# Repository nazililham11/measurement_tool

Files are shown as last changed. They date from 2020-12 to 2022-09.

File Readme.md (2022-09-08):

# Measurement Tool
## Android

***Konfigurasi Alamat Hardware***

Alamat Hardware dapat dilihat dari IP Address yang muncul pada LCD hardware 
Misal IP Address Pada LCD adalah `192.168.0.100` maka alamat nya `ws://192.168.0.100`

### Flowchart komunikasi aplikasi
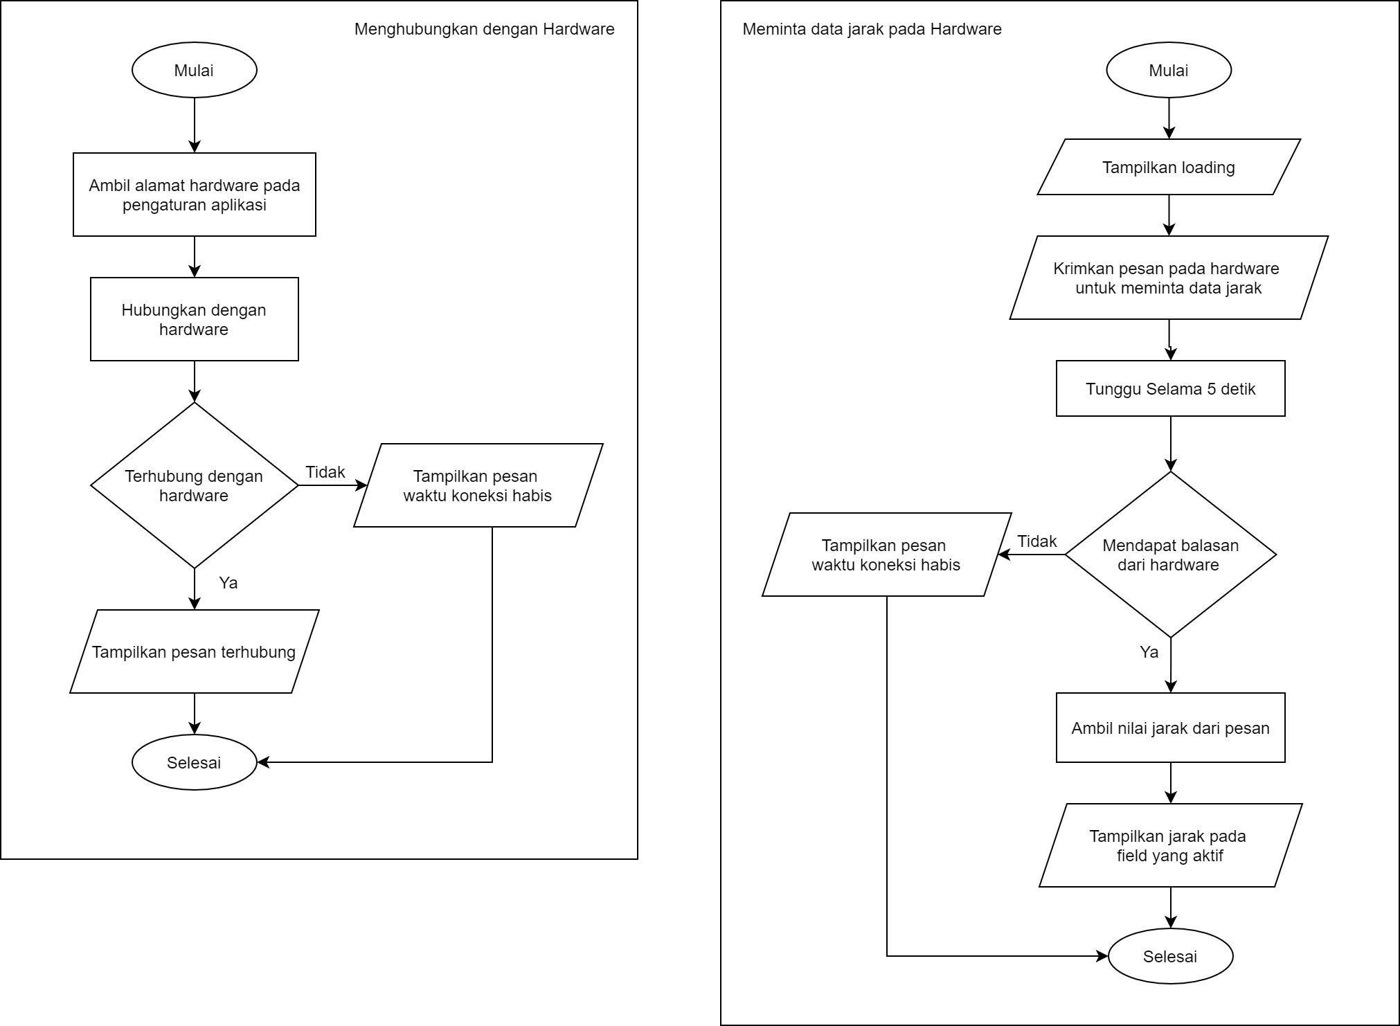
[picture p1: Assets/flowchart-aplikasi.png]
Flowchart Aplikasi


## Arduino

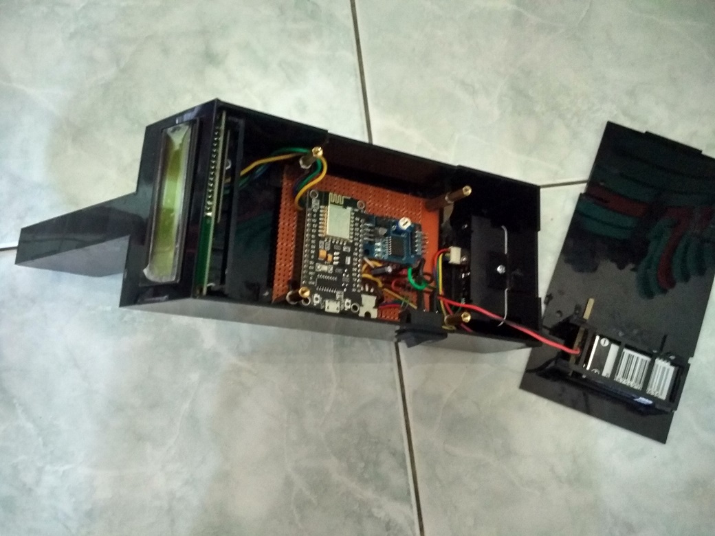
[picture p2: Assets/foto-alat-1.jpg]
Foto Rangkaian

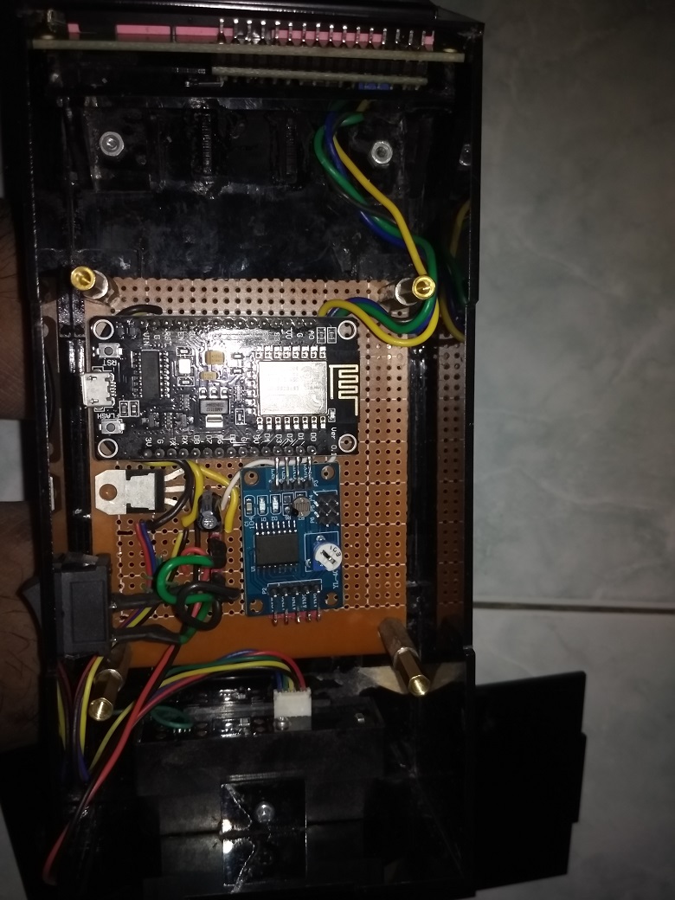
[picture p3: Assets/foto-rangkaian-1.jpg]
Foto Rangkaian

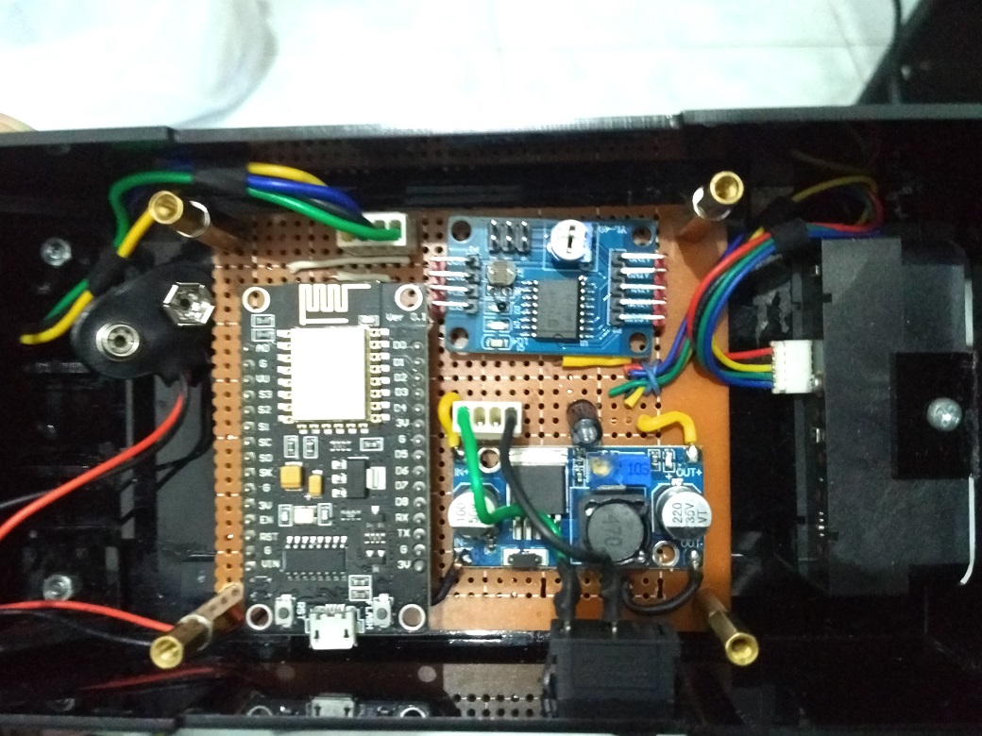
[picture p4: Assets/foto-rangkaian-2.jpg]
Foto Rangkaian


### Komponen
 - NodeMCU ESP8266
 - Sensor Jarak Sharp GP2Y0A710K0F 
 - PCF8591
 - Batterai
 - Saklar
 - LCD 16x2
 - LCD I2C Backpack/LCD to I2C Adapter

### Skema
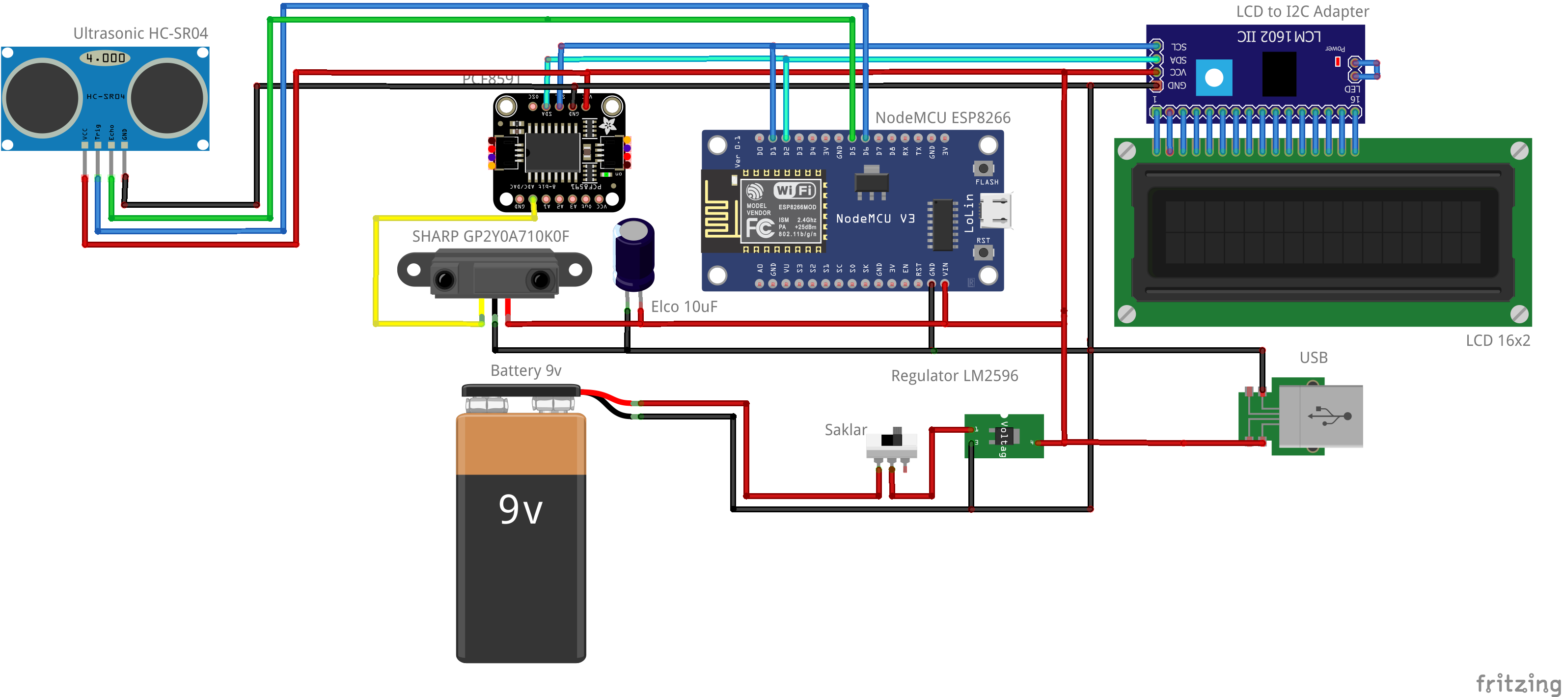
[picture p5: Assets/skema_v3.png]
Skema v2


### Library Program Arduino
 - [ESPAsyncTCP](https://github.com/me-no-dev/ESPAsyncTCP)
 - [ESPAsyncWebServer](https://github.com/me-no-dev/ESPAsyncWebServer)
 - [LiquidCrystal_I2C](https://github.com/johnrickman/LiquidCrystal_I2C)

### Flowchart Program Arduino
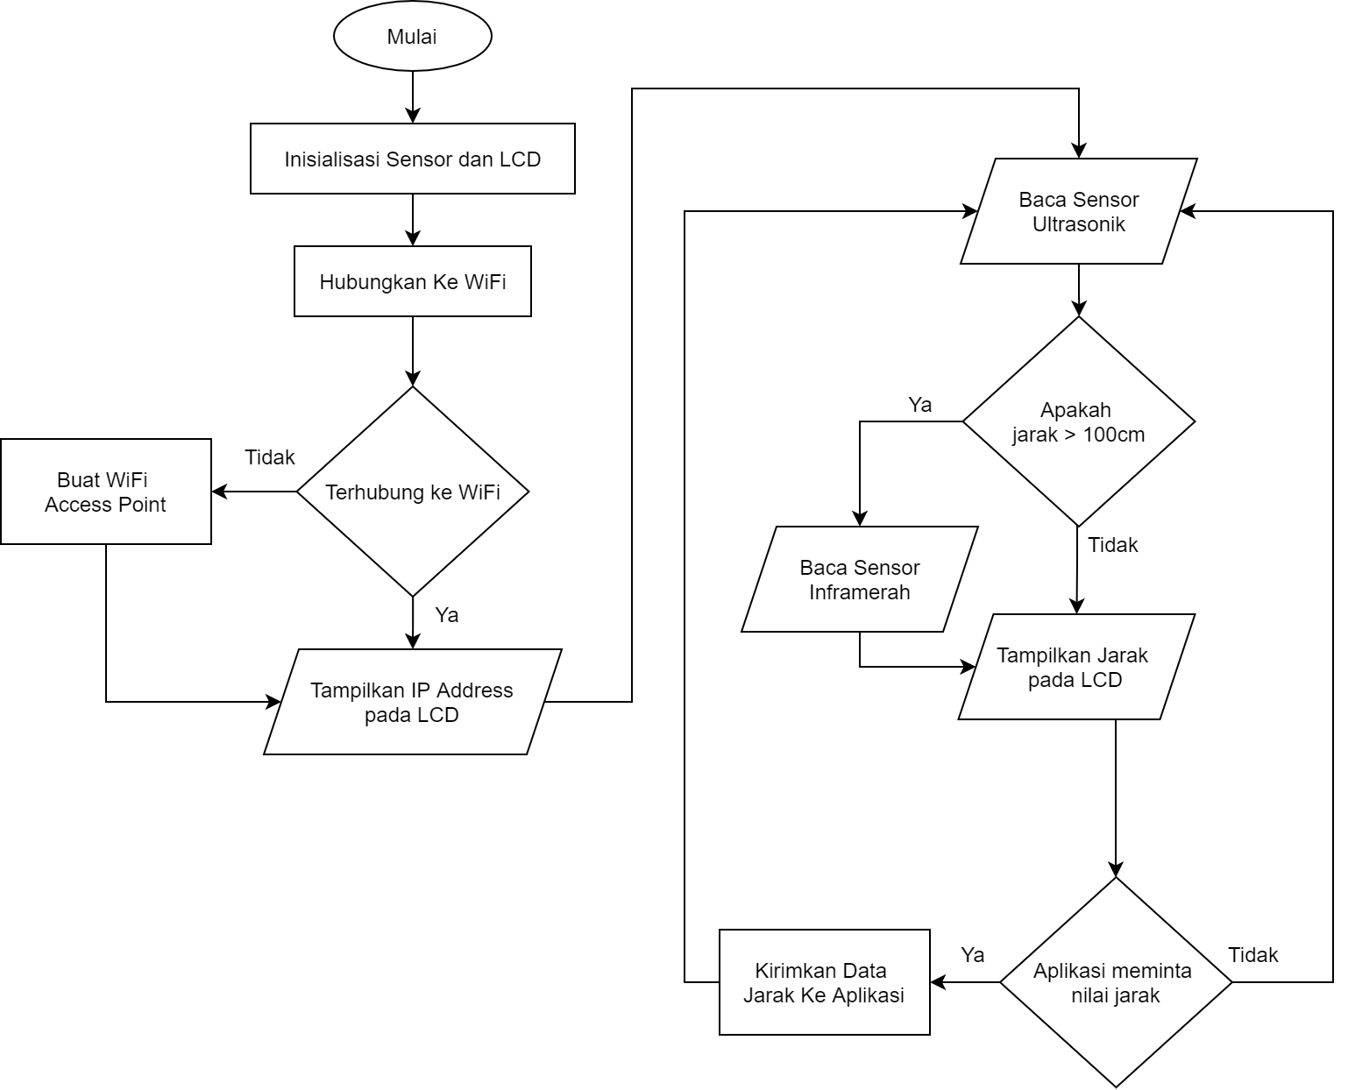
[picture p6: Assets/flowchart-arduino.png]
Flowchart Program Arduino v1


#### Konfigurasi WiFi
Terdapat dua mode pada wifi yaitu `Station` dan `Access Pont`

- Station 		: Terhubung ke wifi 
- Access Point 	: Membuat wifi hotspot

Saat dinyalakan Arduino akan mencoba untkuk terhubung ke WiFi yang ditentukan apabila setelah 15 detik arduino tidak terhubung ke WiFi maka arduino akan membuat Hotspot/Access Point sendiri 

***Konfigurasi Wifi pada mode Access Point***
```
const char* AP_WIFI_SSID            = "SoftAP";             //Access Point SSID
const char* AP_WIFI_PASSWORD        = "12345678";           //Access Point Password
```

***Konfigurasi Wifi pada mode Station***
```
const char* WIFI_SSID               = "MyWifi";				//Wifi SSID
const char* WIFI_PASSWORD           = "12345678";			//Wifi Password
```

#### Konfigurasi Sensor

Proses pengukauran dilakukan sebanyak 10 kali untuk mendapatkan nilai yang akurat. Semakin banyak proses pengukuran maka akan semakin akurat tetapi akan memakan waktu lebih lama

***Konfigurasi banyaknya proses pengukuran***
```
const uint8_t SCAN_TIMES            = 10;
```

#### Konfigurasi LCD
***Konfigurasi Alamat LCD bisa disesuaikan dengan LCD yang digunakan***

Untuk mengetahui alamat lcd bisa menggunakan program `I2C_Address_Scaner`
```
const uint8_t LCD_ADDRESS           = 0x27;
```

## Box Acrylic
Box acrylic didesain dalam bentuk 3D dahulu untuk menentukan desain, tata letak, dan posisi dari komponen, kemudian dibuat versi 2D yang akan digunakan untuk desain potongan acrylic. Proses pembuatan box menggunakan bahan acrylic dengan tebal 2mm dan dipotong menggunakan laser.

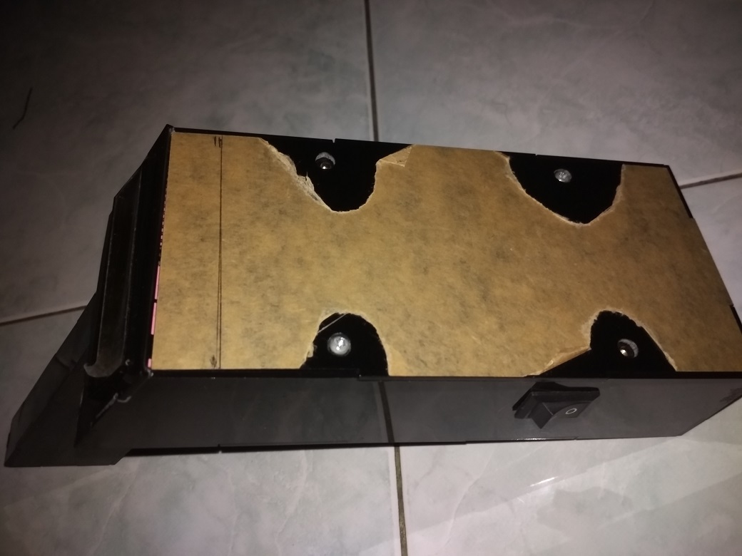
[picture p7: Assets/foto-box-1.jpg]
Foto Box Alat

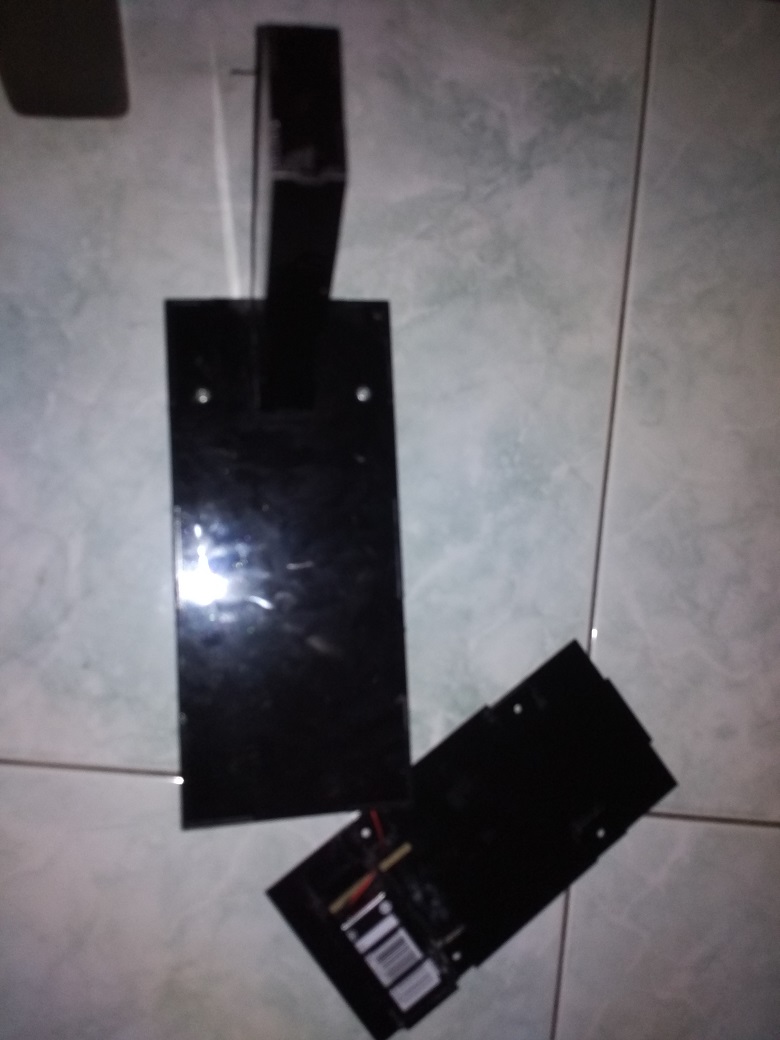
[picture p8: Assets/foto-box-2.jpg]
Foto Box Alat


### Desain 3D Box Acrylic 
Desain 3D box [box.skp](https://github.com/nazililham11/measurement_tool/raw/master/Assets/box.skp) dibuat menggunakan aplikasi google sketchup.
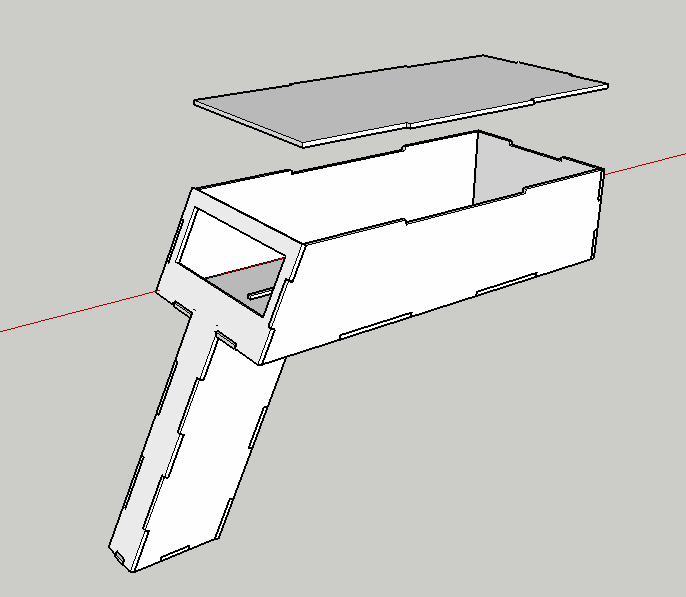
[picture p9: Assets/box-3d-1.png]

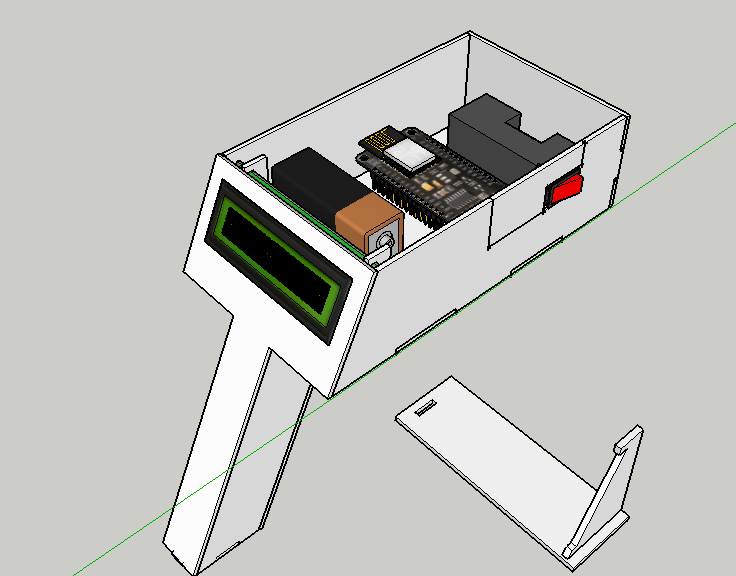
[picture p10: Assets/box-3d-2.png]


### Desain Cutting Acrylic
Desain cutting acrilic [acrylic.cdr](https://github.com/nazililham11/measurement_tool/raw/master/Assets/acrylic.cdr) di buat menggunakan aplikasi corel draw. \
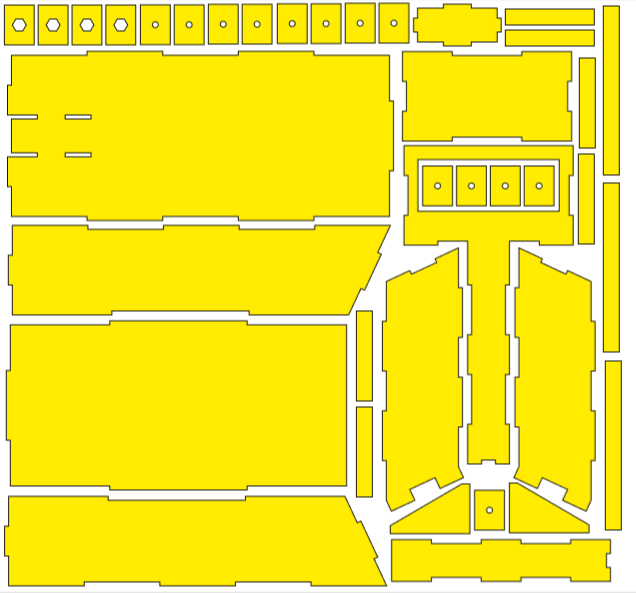
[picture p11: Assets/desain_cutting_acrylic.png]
Desain Cutting Acrylic


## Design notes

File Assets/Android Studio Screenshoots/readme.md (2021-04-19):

### Screenshoots-1
Design Activity/tampilan get started (panduan penggunaan aplikasi)<br>
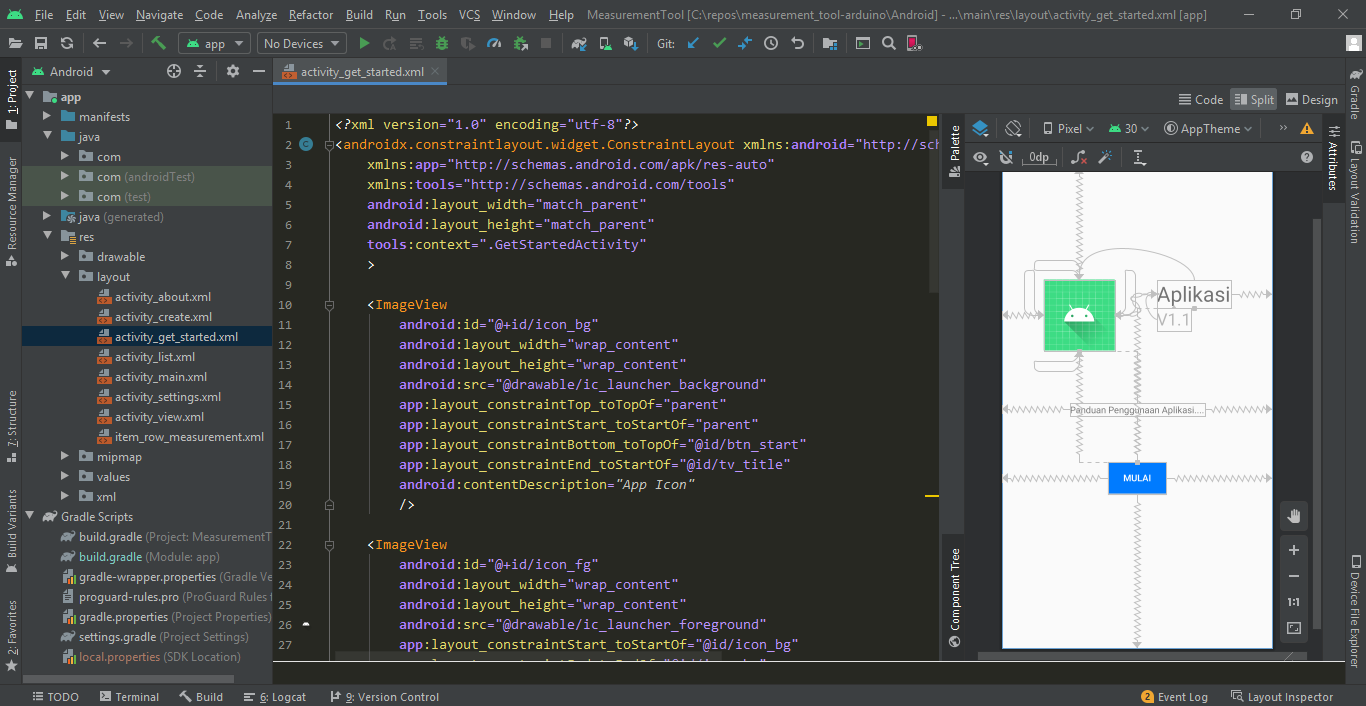
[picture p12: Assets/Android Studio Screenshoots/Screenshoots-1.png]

<br><br><br><br>

### Screenshoots-2
Design Activity/tampilan create (membuat data pengukuran baru)<br>
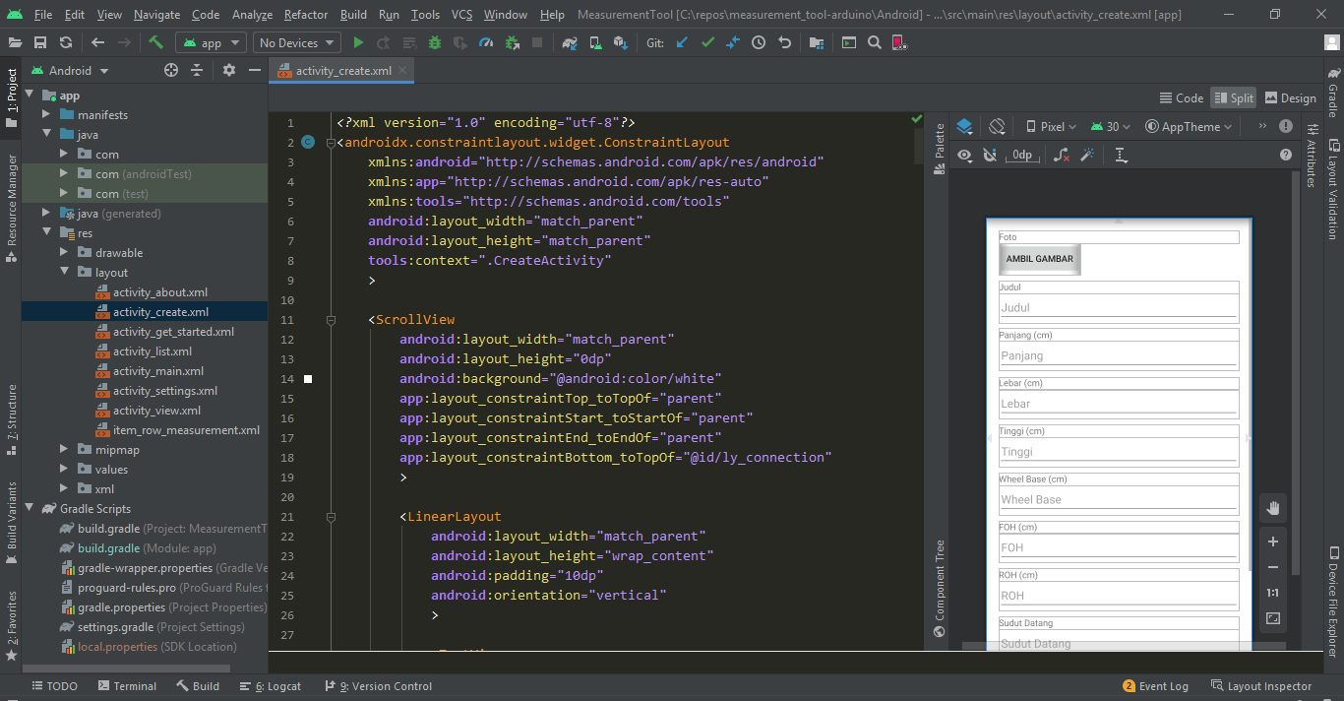
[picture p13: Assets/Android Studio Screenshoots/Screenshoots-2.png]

<br><br><br><br>

### Screenshoots-3
Design Activity/tampilan about (tentang aplikasi)<br>
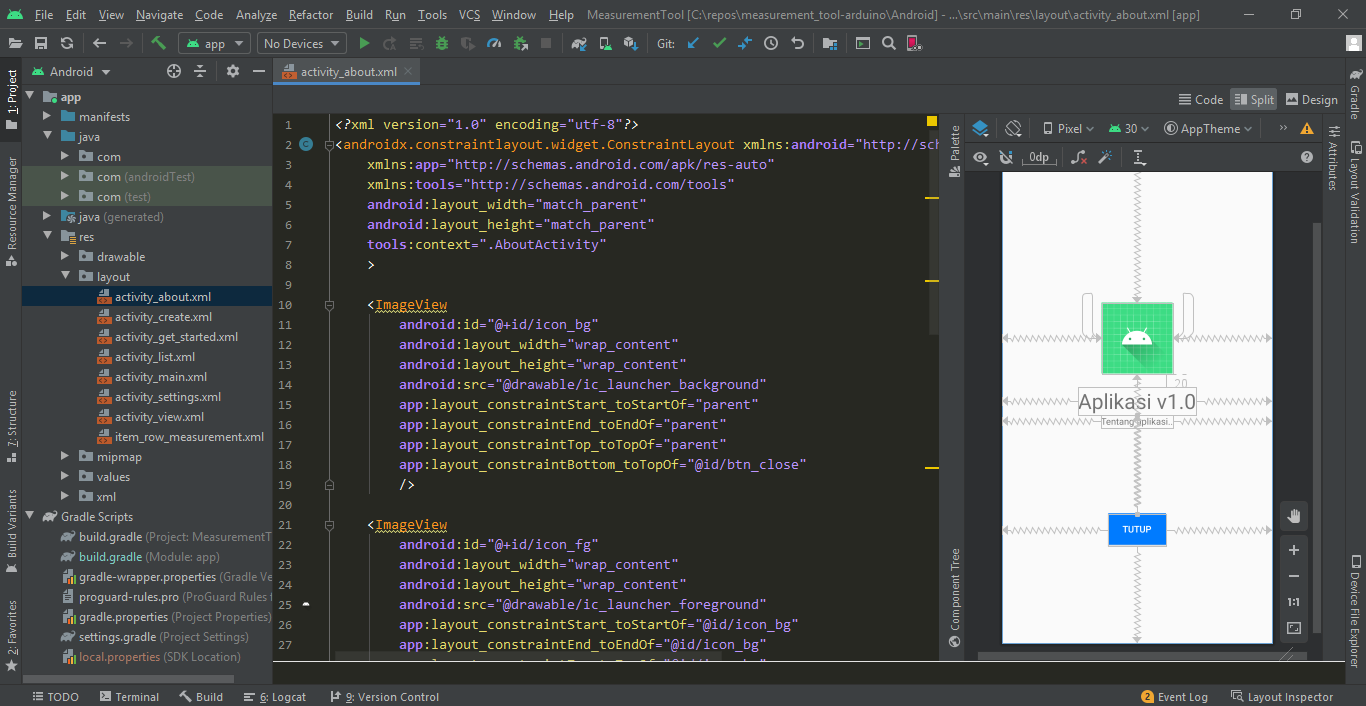
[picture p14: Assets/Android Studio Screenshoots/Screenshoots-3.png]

<br><br><br><br>

### Screenshoots-4
Design Activity/tampilan main (halaman utama)<br>
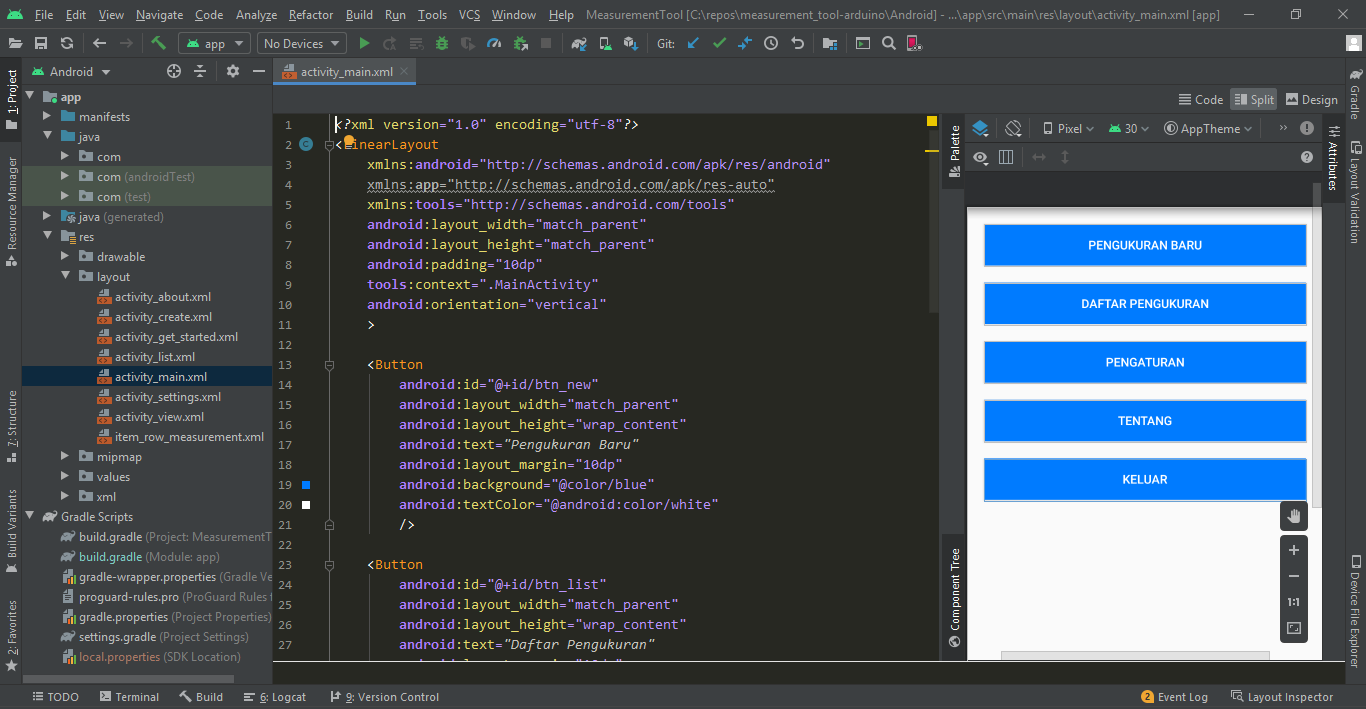
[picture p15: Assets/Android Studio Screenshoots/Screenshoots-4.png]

<br><br><br><br>

### Screenshoots-5
Design Activity/tampilan view (melihat/mengedit/menghapus data yang telah tersimpan)<br>
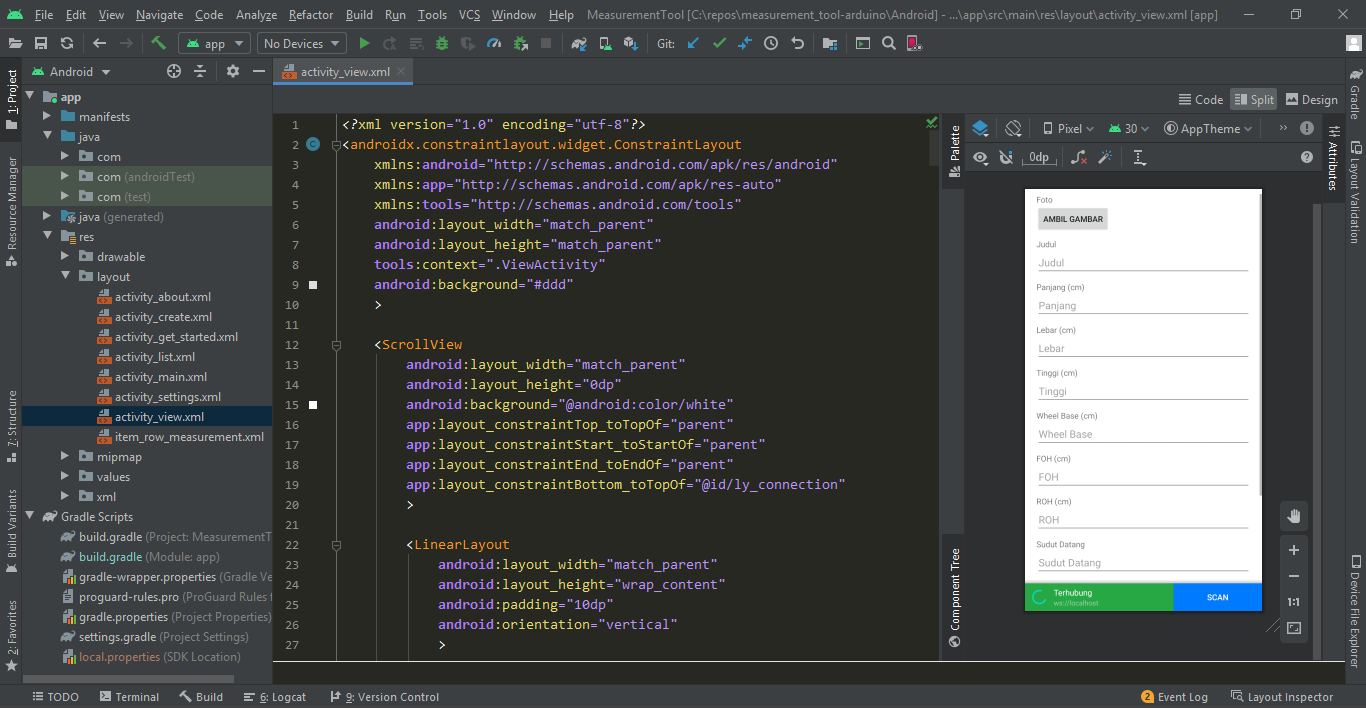
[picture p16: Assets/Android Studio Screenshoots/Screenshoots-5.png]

<br><br><br><br>

### Screenshoots-6
Design item pada list data<br>
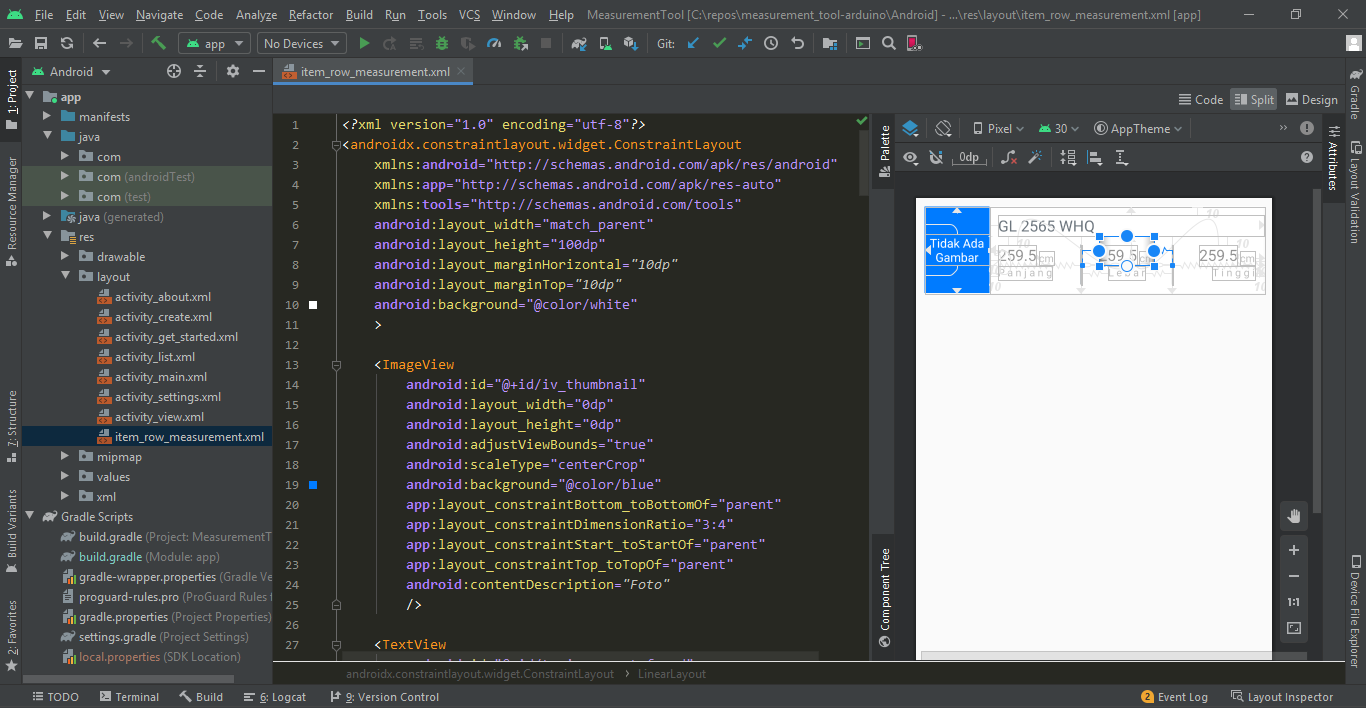
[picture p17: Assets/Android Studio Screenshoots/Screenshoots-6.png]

<br><br><br><br>

### Screenshoots-7
Program backend untuk Activity/tampilan about<br>
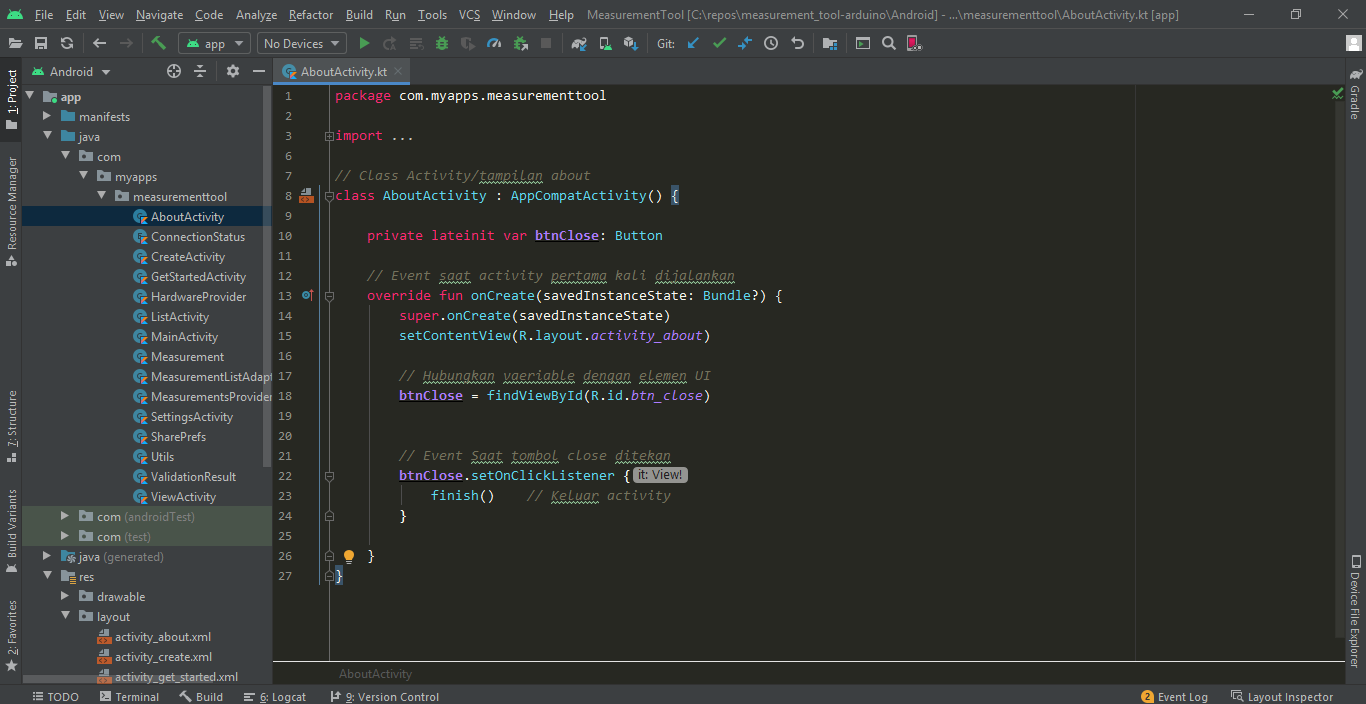
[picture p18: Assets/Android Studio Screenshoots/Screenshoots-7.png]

<br><br><br><br>

### Screenshoots-8
Program backend untuk Activity/tampilan create<br>
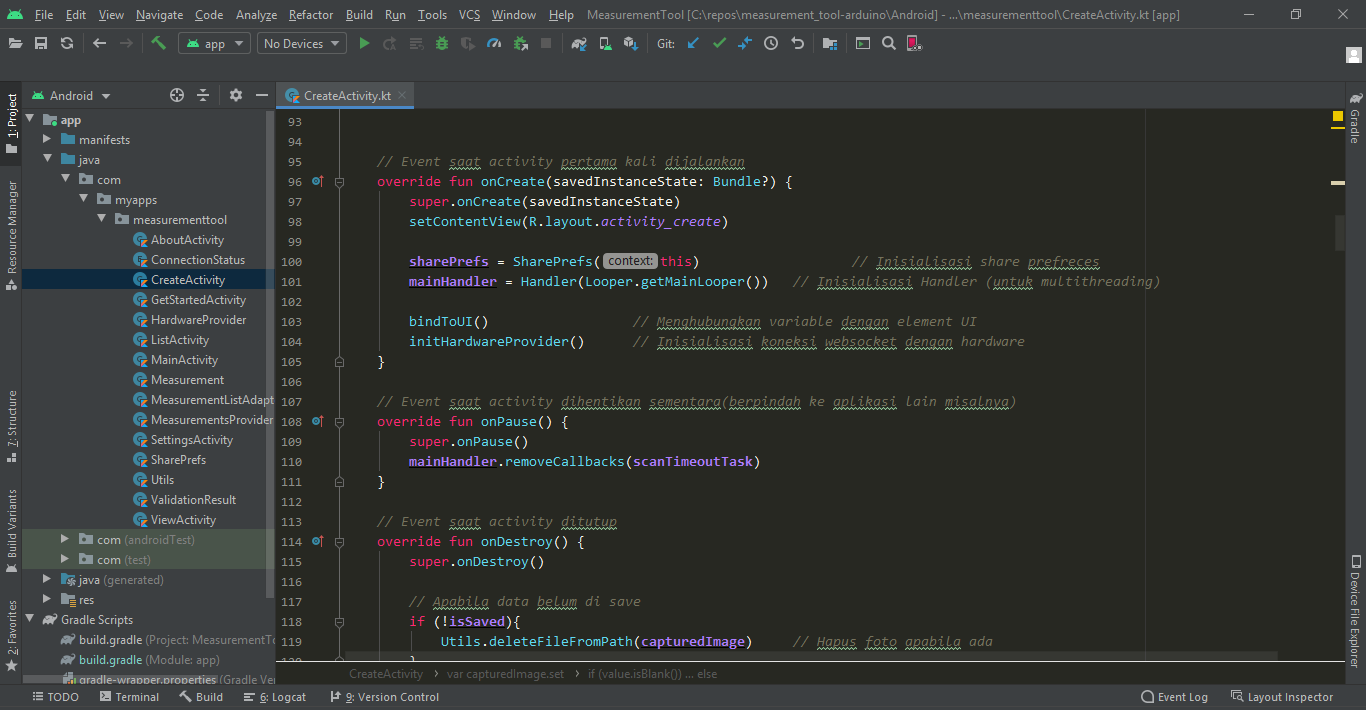
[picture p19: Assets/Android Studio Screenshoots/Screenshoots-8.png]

<br><br><br><br>

### Screenshoots-9
Program backend untuk Activity/tampilan get started<br>
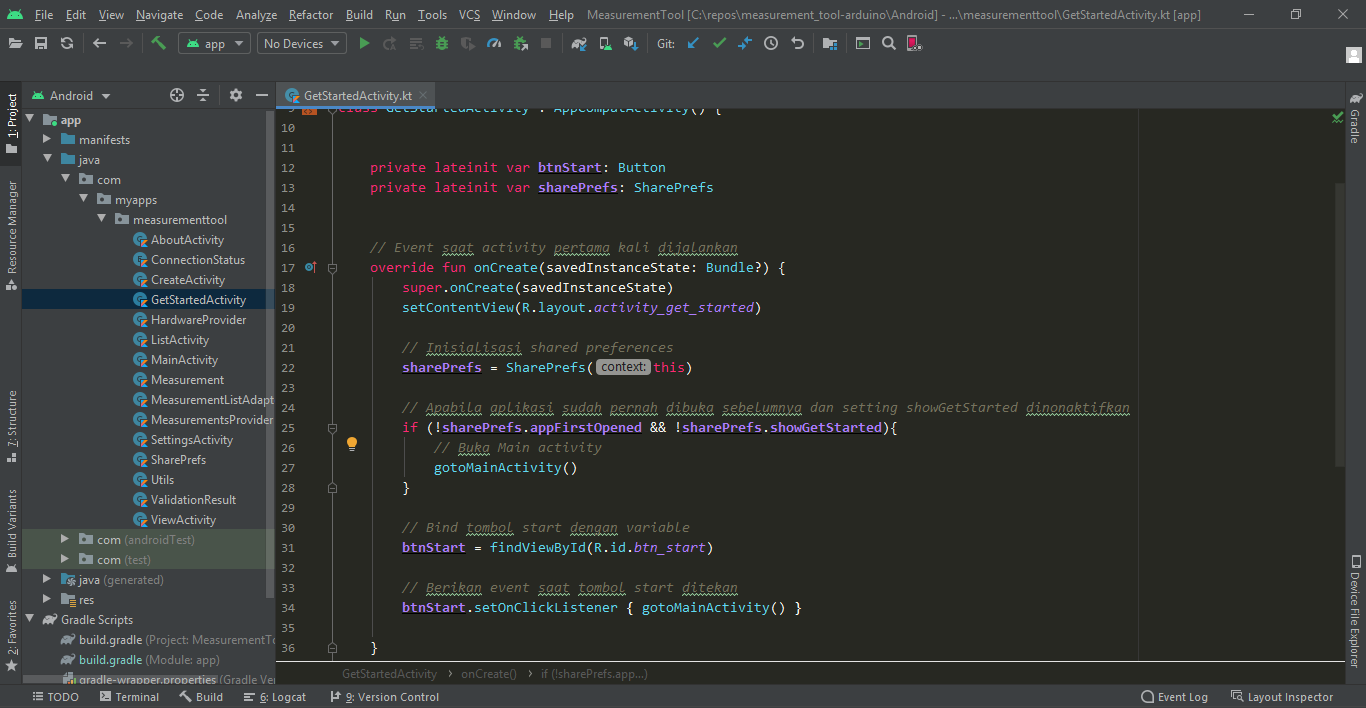
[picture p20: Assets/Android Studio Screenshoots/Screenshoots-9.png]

<br><br><br><br>

### Screenshoots-10
Program backend untuk Activity/tampilan list<br>
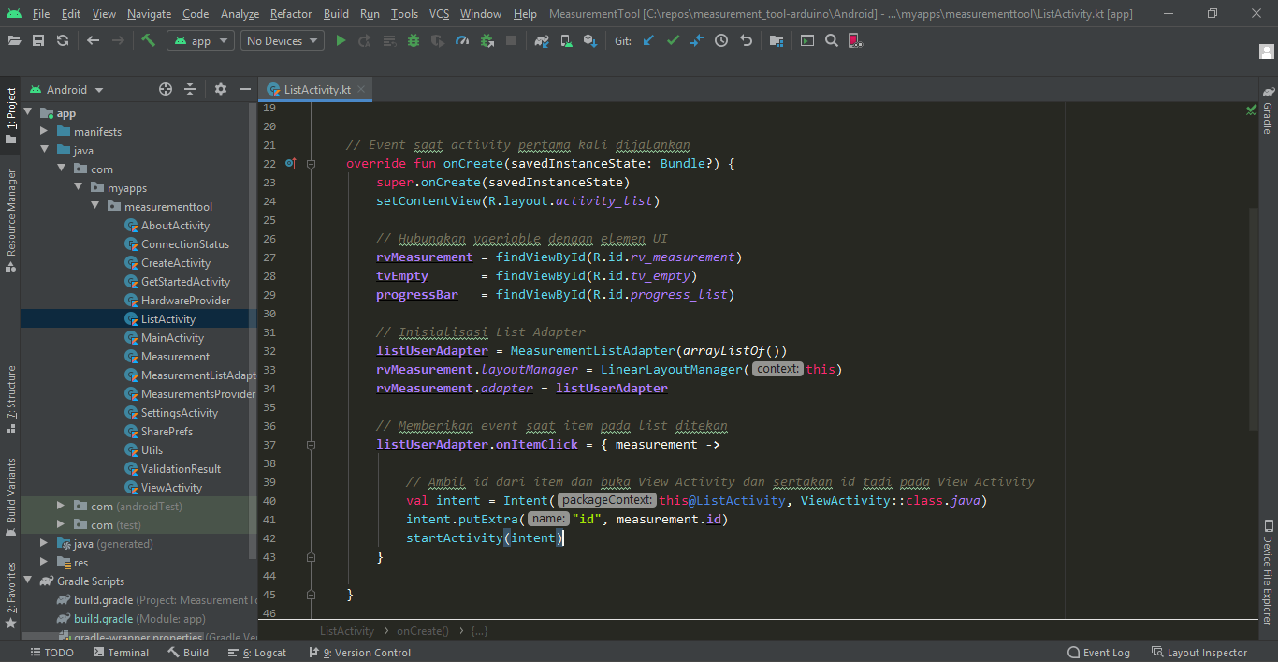
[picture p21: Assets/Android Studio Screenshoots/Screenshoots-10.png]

<br><br><br><br>

### Screenshoots-11
Program backend untuk Activity/tampilan main<br>
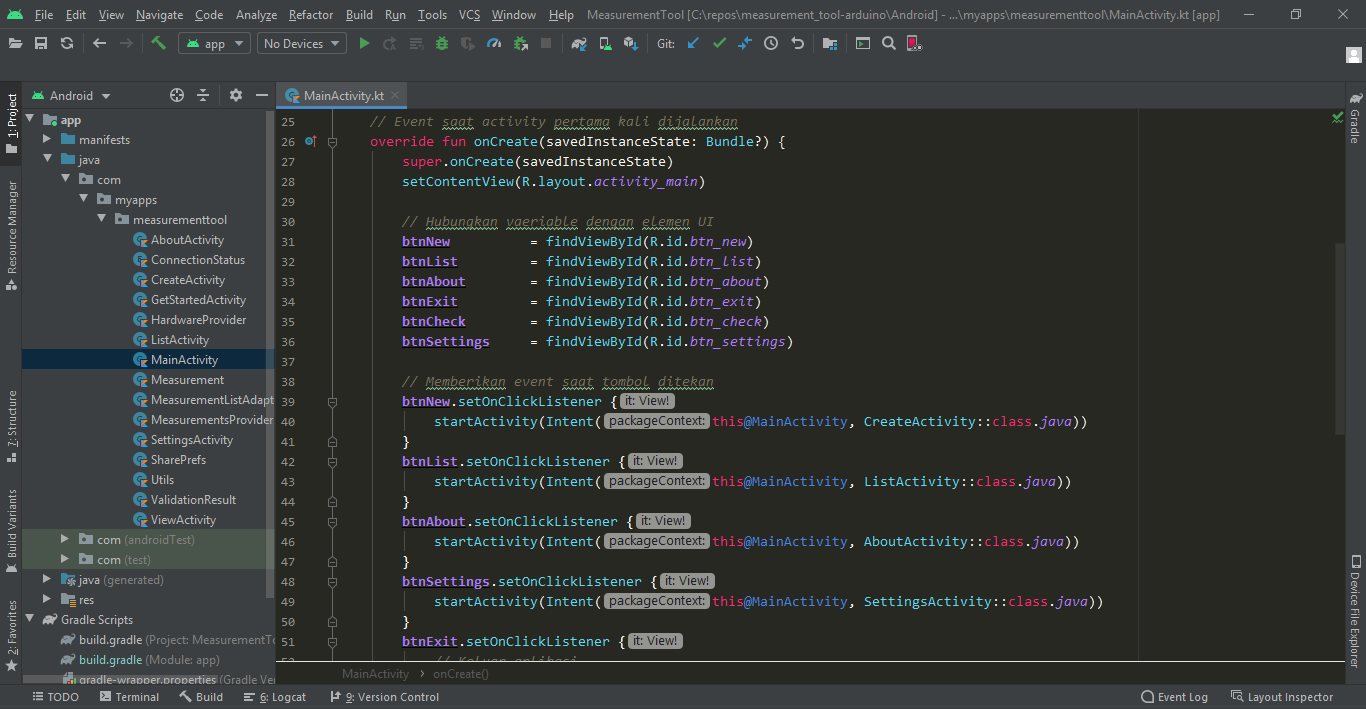
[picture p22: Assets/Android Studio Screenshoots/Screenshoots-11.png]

<br><br><br><br>

### Screenshoots-12
Program backend untuk Activity/tampilan settings<br>
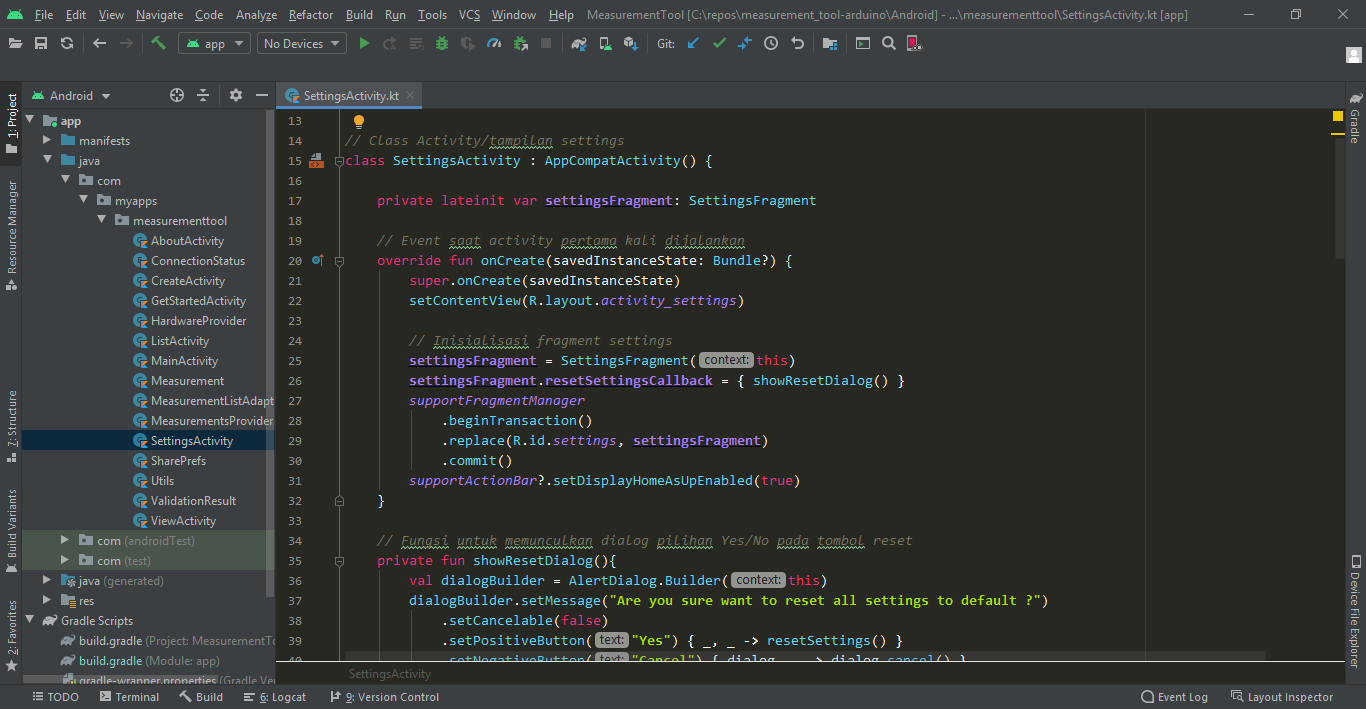
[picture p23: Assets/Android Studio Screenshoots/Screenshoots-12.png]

<br><br><br><br>

### Screenshoots-13
Program backend untuk Activity/tampilan view<br>
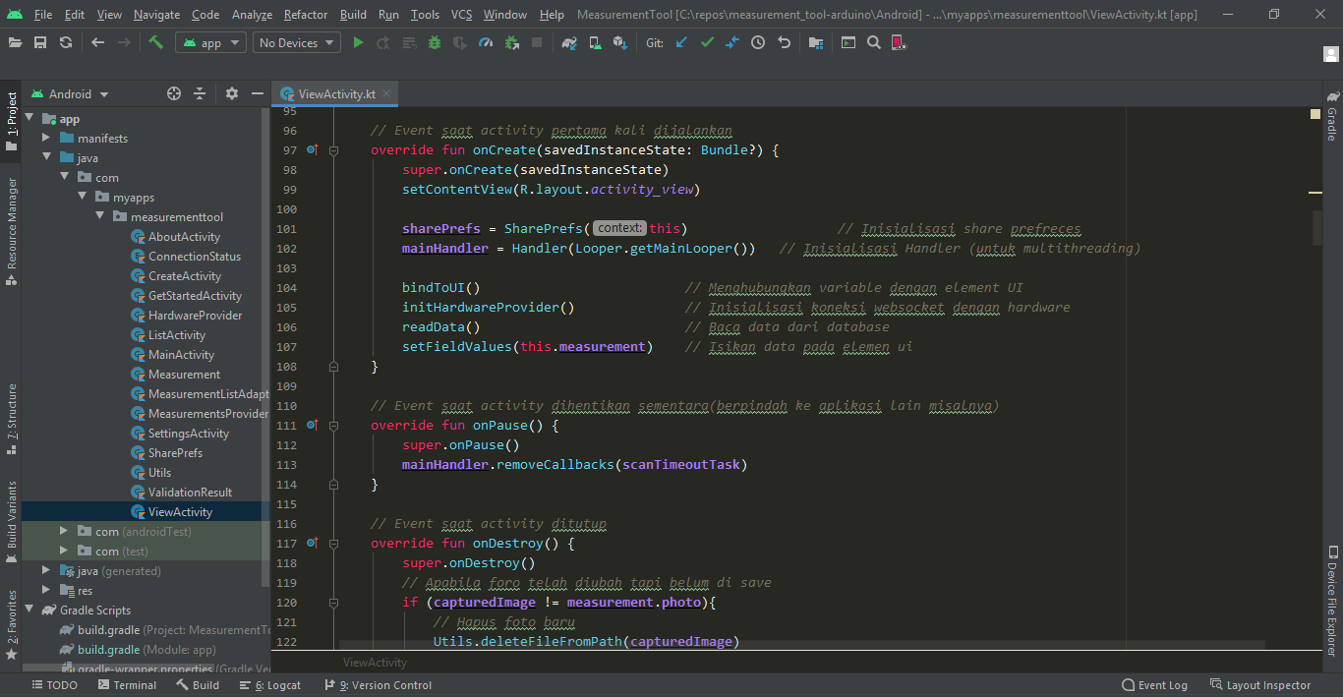
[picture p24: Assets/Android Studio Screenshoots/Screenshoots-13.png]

<br><br><br><br>

### Screenshoots-14
File konfigurasi untuk setiap string/teks pada aplikasi<br>
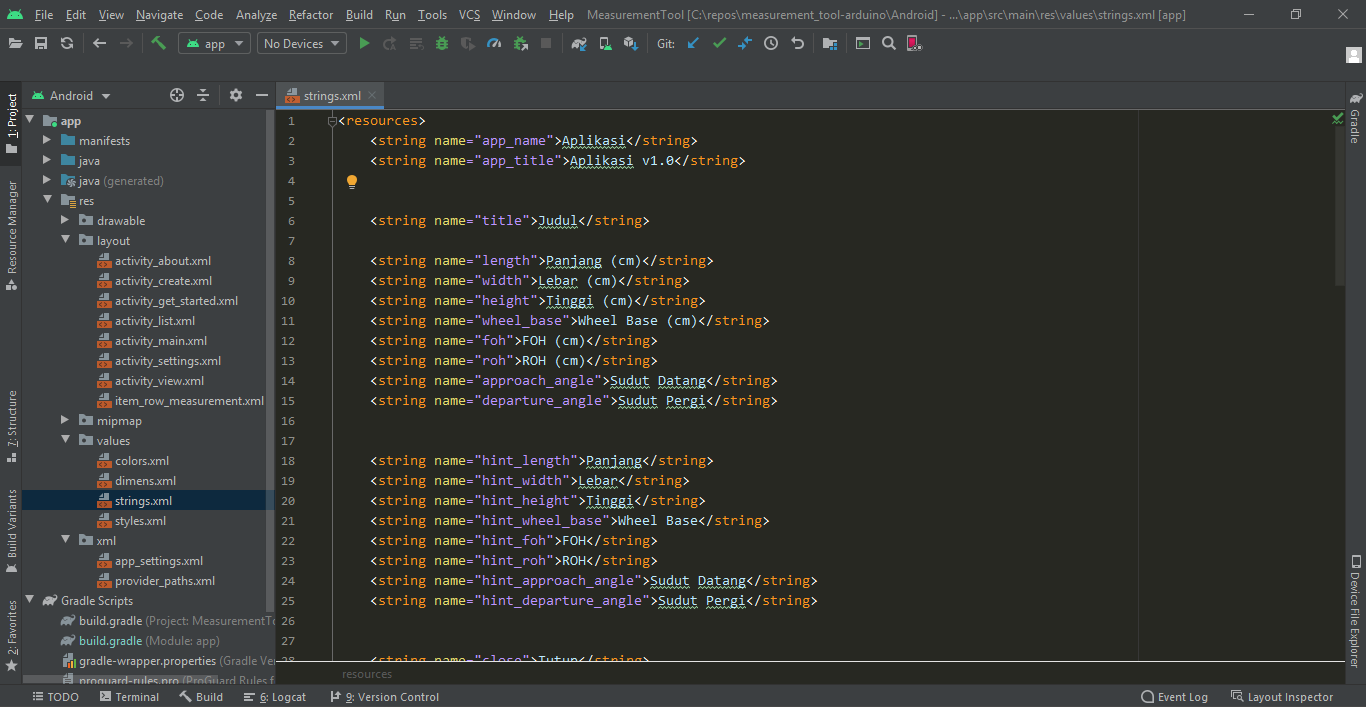
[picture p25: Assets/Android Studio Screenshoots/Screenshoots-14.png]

<br><br><br><br>

### Screenshoots-15
File konfigurasi untuk menentukan elemen yang terdapat dalam settings<br>
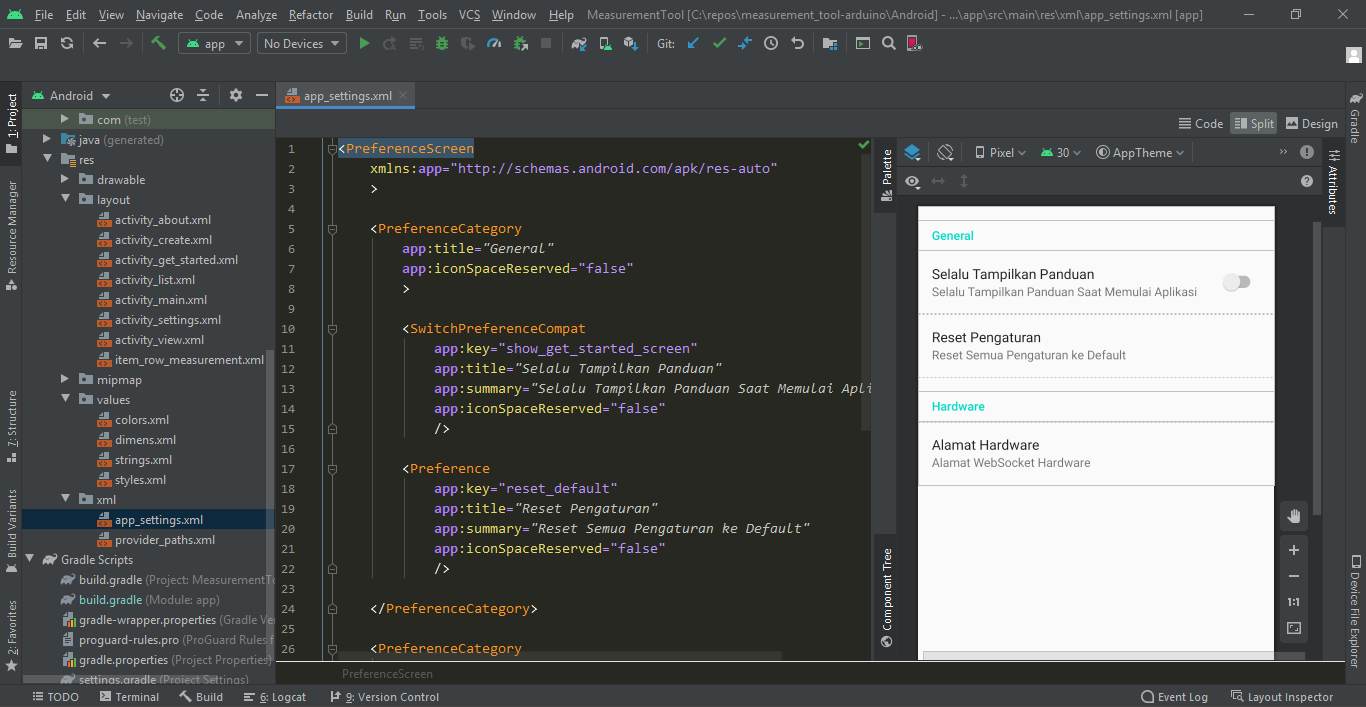
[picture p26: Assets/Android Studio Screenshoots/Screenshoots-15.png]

<br><br><br><br>

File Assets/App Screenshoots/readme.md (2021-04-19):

### Screenshoots-1
Tampilan panduan penggunaan aplikasi<br>
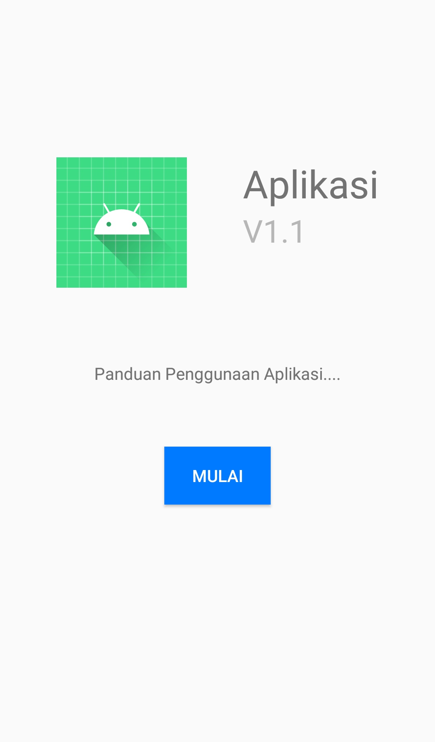
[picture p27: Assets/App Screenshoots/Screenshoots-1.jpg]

<br><br><br>

### Screenshoots-2
Tampilan informasi tentang aplikasi<br>
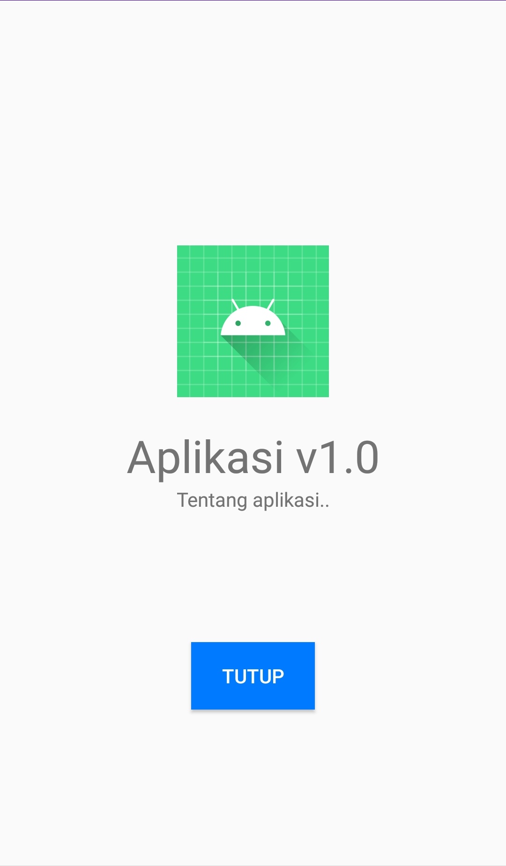
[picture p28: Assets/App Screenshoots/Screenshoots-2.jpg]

<br><br><br>

### Screenshoots-3
Tampilan pengaturan aplikasi<br>
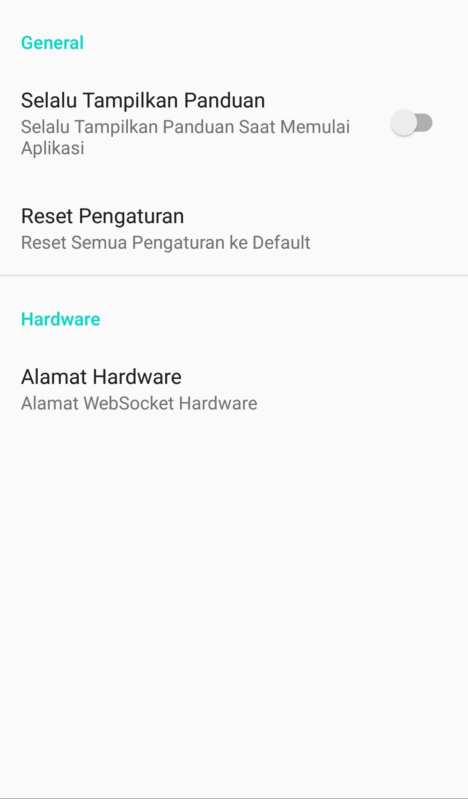
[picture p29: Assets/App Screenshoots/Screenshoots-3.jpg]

<br><br><br>

### Screenshoots-4
Tampilan daftar pengukuran yang telah tersimpan<br>
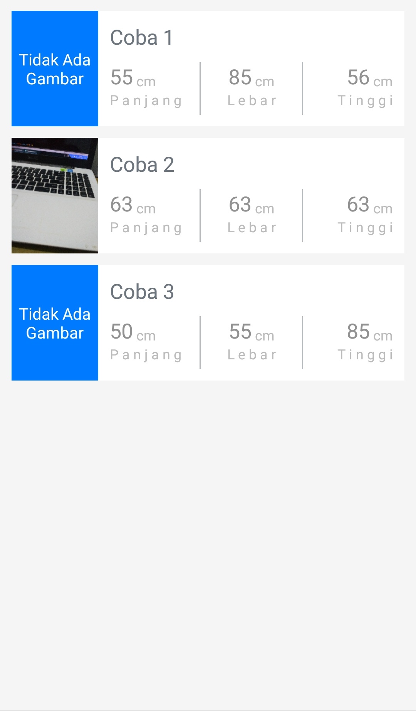
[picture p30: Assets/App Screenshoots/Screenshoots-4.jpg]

<br><br><br>

### Screenshoots-5
Tampilan membuat data pengukuran baru<br>
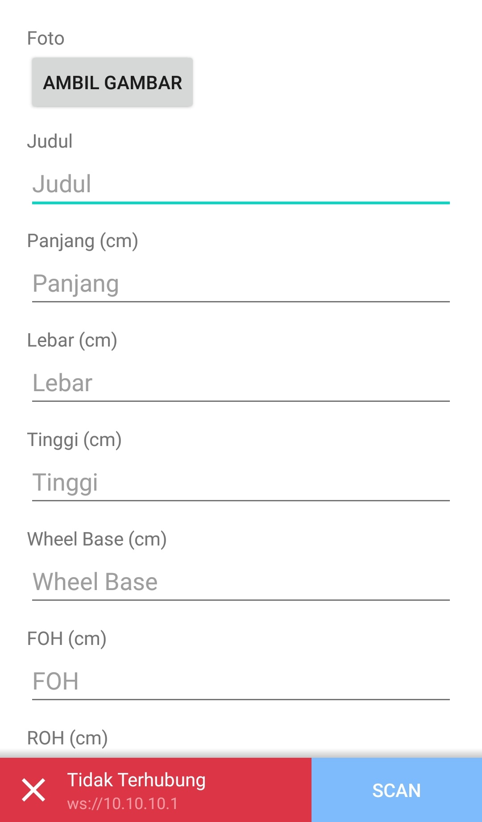
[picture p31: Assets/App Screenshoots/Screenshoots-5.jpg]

<br><br><br>

### Screenshoots-6
Tampilan melihat/mengedit/menghapus data yang tersimpan (tidak ada foto)<br>
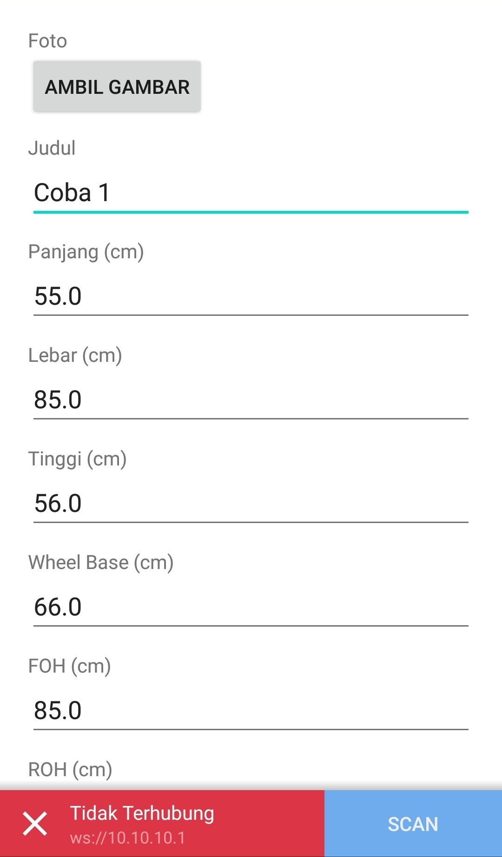
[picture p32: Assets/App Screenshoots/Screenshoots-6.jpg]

<br><br><br>

### Screenshoots-7
Tampilan melihat/mengedit/menghapus data yang tersimpan (dengan foto)<br>
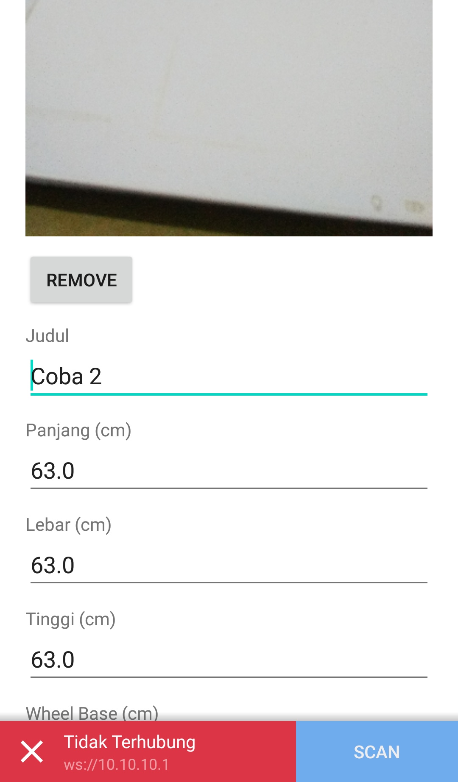
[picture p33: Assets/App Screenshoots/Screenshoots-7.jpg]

<br><br><br>

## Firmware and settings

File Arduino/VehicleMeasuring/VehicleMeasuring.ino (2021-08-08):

#include <ESP8266WiFi.h>				// Untuk menghubungkan dengan WIFI atau membuat WIFI access point
#include <ESPAsyncTCP.h>				// Untuk melakukan komunikasi TCP (protokol komunikasi pada jaringan wifi)
#include <ESPAsyncWebServer.h>			// Untuk menjalankan server WebSocket pada mikrokontroler
#include <Wire.h> 						// Untuk berkomunikasi melalui protokol I2C (protokol kamunikasi untuk modul LCD dan modul PCF8591)
#include <LiquidCrystal_I2C.h>			// Untuk berkomunikasi dengan modul LCD dan mempermudah mengoperasikan modul LCD

#define SENSOR_INFRARED		0
#define SENSOR_ULTRASONIC	1
#define OUT_OF_RANGE 		0
#define PCF8591 			(0x90 >> 1)
#define DEBUG_BAUD_RATE 	115200

// kecepatan suara (20'C)  => 343 m/s => 34300 cm/s 
// 1 detik = 1000000 uS (micro second)
// 34300 / 1000000 = 0.0343 cm/uS
#define SOUND_VELOCITY 		0.034
#define TRIGGER_PIN  		12 
#define ECHO_PIN     		14 
#define MAX_SONAR_DISTANCE 	100 


// ----------------------------------------------------------------------------------------
// Variabel Konfigurasi WIFI
// ----------------------------------------------------------------------------------------
const char* AP_WIFI_SSID            = "SoftAP";             // Access Point SSID
const char* AP_WIFI_PASSWORD        = "12345678";           // Access Point Password

const char* WIFI_SSID               = "Redmi";              // Wifi SSID
const char* WIFI_PASSWORD           = "12345678";           // Wifi Password

const IPAddress ap_ipAddress        (10, 10, 10, 1);        // Server IP Address
const IPAddress ap_gateway          (10, 10, 10, 1);        // Server Gateway
const IPAddress ap_subnetMask       (255, 255, 255, 0);     // Server Subnetmask                                   

const uint8_t WIFI_CONNECT_TIMEOUT  = 15;                   // Detik

const uint8_t WEBSOCKET_PORT        = 80;



// ----------------------------------------------------------------------------------------
// Variabel Konfigurasi LCD 
// ----------------------------------------------------------------------------------------
const uint8_t LCD_ADDRESS           = 0x27;
const uint8_t LCD_COLS              = 16;
const uint8_t LCD_ROWS              = 2;




// ----------------------------------------------------------------------------------------
// Deklarasi Variable, Function, Object
// ----------------------------------------------------------------------------------------

unsigned int distance; 
float voltage;
bool access_point_mode;
bool sensor_used;

LiquidCrystal_I2C lcd(LCD_ADDRESS, LCD_COLS, LCD_ROWS);  

// Create AsyncWebServer object on port 80
AsyncWebServer server(80);
AsyncWebSocket ws("/");


void wifi_init();
void wifi_softap_start();
void lcd_init();
void lcd_show_distance();
void websocket_send_distance();
void websocket_handle_message(void *arg, uint8_t *data, size_t len);
void websocket_onEvent(AsyncWebSocket *server, AsyncWebSocketClient *client, AwsEventType type, void *arg, uint8_t *data, size_t len);
void websocket_init();
uint8_t pcf8591_read();
uint16_t read_distance_cm();
uint16_t to_infrared_distance(uint16_t value);
uint16_t read_median(uint8_t it, bool isSonar);   
float ping_cm();




// ----------------------------------------------------------------------------------------
// Inisialisasi Program
// ----------------------------------------------------------------------------------------
void setup(){
	
	pinMode(TRIGGER_PIN, OUTPUT); 	// Sets the trigPin as an Output
  	pinMode(ECHO_PIN, INPUT); 		// Sets the echoPin as an Input

    // Memulai Komunikasi Serial untuk keperluan Debug
    Serial.begin(DEBUG_BAUD_RATE);
  
    
    lcd_init();         // Memulai komunikasi dengan modul LCD 
    wifi_init();        // Inisialisasi WIFI
    websocket_init();   // Inisialisasi Protokol Websocket

    // Memulai Server Websocket
    server.begin();
}




// ----------------------------------------------------------------------------------------
// Program Loop
// ----------------------------------------------------------------------------------------
void loop() {

	// Baca Jarak dengan sensor ultrasonic sebanyak 10 Kali		
	distance = read_median(10, SENSOR_ULTRASONIC);
	sensor_used = SENSOR_ULTRASONIC;
	
	// jika jarak lebih dari jarak maksimum ultrasonik
	if (distance > MAX_SONAR_DISTANCE){
    	// Baca Jarak dengan sensor infrared sebanyak 100 Kali		
    	distance = read_median(100, SENSOR_INFRARED);
    	sensor_used = SENSOR_INFRARED;
	}

    // Update Tampilan LCD 
    lcd_update();


    // Tampilkan Pada Konsol Serial untuk proses Debug
    Serial.print("Distance :"+String(distance)+"cm, ");
    Serial.print("Voltage :"+String(voltage));
    Serial.println();

    // Cek apakah aplikasi meminta data jarak
    ws.cleanupClients();

    // Tunda 100 ms
    delay(100);
}





// ----------------------------------------------------------------------------------------
// Inisialisasi WIFI
// ----------------------------------------------------------------------------------------
void wifi_init() {

    // Tampilkan pesan pada LCD dan Konsol Serial
	lcd.clear();
	lcd_print("Try connect to", 0, 0);
    Serial.println("Try connect to WiFi \"" + String(WIFI_SSID) + "\"");

    // Hubungkan ke wifi 
    WiFi.mode(WIFI_STA);
    WiFi.begin(WIFI_SSID, WIFI_PASSWORD);

    // Tunggu sesuai nilai timeout serta update tampilan LCD
    for (int i = 0; i < WIFI_CONNECT_TIMEOUT && WiFi.status() != WL_CONNECTED; i++) {
        Serial.print(".");
        delay(1000);
        
        if (i % 3 == 0){
        	lcd_print(String(WIFI_SSID) + ".  ", 0, 1);
        } else if (i % 3 == 1) {
        	lcd_print(String(WIFI_SSID) + ".. ", 0, 1);
        } else {
        	lcd_print(String(WIFI_SSID) + "...", 0, 1);
        }

    }
    Serial.println(); 

    // Apabila wifi gagal terhubung 
    if (WiFi.status() != WL_CONNECTED){

        // Tamplkan pesan pada LCD dan konsol serial
    	lcd.clear();
		lcd_print("Cannot connect", 0, 0);
		lcd_print("to "+ String(WIFI_SSID), 0, 1);
		
		delay(1500);

        Serial.println("Cannot connect to Wifi");

        // Beralih ke mode Access Point 
        wifi_softap_start();


    // Apabila wifi berhasil terhubung
    } else if (WiFi.status() == WL_CONNECTED) {

        // Tampilkan pesan pada LCD dan konsol serial
    	lcd.clear();
		lcd_print("Connected to", 0, 0);
		lcd_print(String(WIFI_SSID), 0, 1);
		
		delay(1500);

        Serial.println("WiFi connected");
        Serial.print("IP address: ");
        Serial.println(WiFi.localIP());   //You can get IP address assigned to ESP
        access_point_mode = false;
    }
}




// ----------------------------------------------------------------------------------------
// Memulai Mode Access Point
// ----------------------------------------------------------------------------------------
void wifi_softap_start() {
    
    // Tampilkan pesan pada LCD dan konsol serial
    lcd.clear();
	lcd_print("Starting SoftAP", 0, 0);
	lcd_print(AP_WIFI_SSID, 0, 1);
    
    Serial.print("Starting SoftAP");
	
	delay(1500);
    
    // Nyalakan Access Point
    WiFi.mode(WIFI_AP);
    WiFi.softAPConfig(ap_ipAddress, ap_gateway, ap_subnetMask);   // subnet FF FF FF 00
    WiFi.softAP(AP_WIFI_SSID, AP_WIFI_PASSWORD);
    
    // Tampilkan pesan pada LCD dan konsol serial
	lcd.clear();
	lcd_print("SSID:"+String(AP_WIFI_SSID), 0, 0);
	lcd_print("Pass:"+String(AP_WIFI_PASSWORD), 0, 1);

    Serial.print("AP IP address: ");
    Serial.println(WiFi.softAPIP());
    Serial.println("Done");

    access_point_mode = true;

    delay(3000);
}



// ----------------------------------------------------------------------------------------
// Inisialisasi LCD 
// ----------------------------------------------------------------------------------------
void lcd_init(){
    lcd.init();         // Memulai komunikasi dengan modul LCD 
    lcd.backlight();    // Menyalakan Backlight
    lcd.clear();        // Bersihkan tampilan LCD 
}



// ----------------------------------------------------------------------------------------
// Memperbarui tampilan pada LCD 
// ----------------------------------------------------------------------------------------
void lcd_update(){
	String text = "";

    // Tampilan jarak normal
	if (distance != OUT_OF_RANGE)
    text = "Jarak: " + String(distance) + "cm " + (sensor_used ? "(U)" : "(I)");
    
    // Tampilan jarak apabila diluar batas pengukuran
    else text = "Jarak: Out Range";
    
    // Tampilkan text jarak pada baris 0 kolom 0
    lcd_print(text, 0, 0);



    // Tampilan status wifi dan ip address saat mode access point
    if (access_point_mode)
    text = "AP|" + WiFi.softAPIP().toString() + "    "; 
    
    // Tampilan status wifi dan ip address saat mode station
    else text = "ST|" + WiFi.localIP().toString() + "    ";

    // Tampilkan status wifi dan ip address pada kolom 0 baris 1
    lcd_print(text, 0, 1);

}



// ----------------------------------------------------------------------------------------
// Menampilkan pesan pada LCD 
// ----------------------------------------------------------------------------------------
void lcd_print(String str, uint8_t col, uint8_t row) {
    lcd.setCursor(col, row);    // Pindahkan kursor 
    lcd.print(str);             // Tampilkan text
}




// ----------------------------------------------------------------------------------------
// Protokol websocket untuk mengirimkan data jarak ke aplikasi 
// ----------------------------------------------------------------------------------------
void websocket_send_distance() {
    String response = "{\"dst\":" + String(distance) + "}";
    ws.textAll(response);
}



// ----------------------------------------------------------------------------------------
// Protokol websocket untuk mengirimkan data status device ke aplikasi
// ----------------------------------------------------------------------------------------
void websocket_send_status() {
    String response = "{";
    if (access_point_mode){
        response += "\"mode\":\"AP\",";
        response += "\"ssid\":\"" + String(AP_WIFI_SSID) + "\",";
        response += "\"pass\":\"" + String(AP_WIFI_PASSWORD) + "\",";
        response += "\"ip\":\"" + WiFi.softAPIP().toString() + "\",";
    } else {
        response += "\"mode\":\"STA\",";
        response += "\"ssid\":\"" + String(WIFI_SSID) + "\",";
        response += "\"pass\":\"" + String(WIFI_PASSWORD) + "\",";
        response += "\"ip\":\"" + WiFi.localIP().toString() + "\",";
    }
    response += "\"uptime\":" + String(millis());   
    response += "}";       
    ws.textAll(response);
}


// ----------------------------------------------------------------------------------------
// Protokol websocket untuk mengirimkan data jarak ke aplikasi 
// ----------------------------------------------------------------------------------------
void websocket_handle_message(void *arg, uint8_t *data, size_t len) {
    AwsFrameInfo *info = (AwsFrameInfo*)arg;
    if (info->final && info->index == 0 && info->len == len && info->opcode == WS_TEXT) {
        data[len] = 0;

        // Apabila menerima data yang berisi perintah 'scan' 
        if (strcmp((char*)data, "scan") == 0) 
        websocket_send_distance();      // Kirimkan data jarak
        
        // Apabila menerima data yang berisi perintah 'status' 
        else if (strcmp((char*)data, "status") == 0) 
        websocket_send_status();        // Kirimkan data status
    }
}



// ----------------------------------------------------------------------------------------
// Protokol websocket saat terjadinya event (dibuka/ditutupnya komunikasi, menerima data, terjadi error)
// ----------------------------------------------------------------------------------------
void websocket_onEvent(AsyncWebSocket *server, AsyncWebSocketClient *client, 
    AwsEventType type, void *arg, uint8_t *data, size_t len) {

    if (type == WS_EVT_CONNECT) {
        Serial.println("Connnection Opened");
        Serial.printf("WebSocket client #%u connected from %s\n", client->id(), client->remoteIP().toString().c_str());
    } else if (type == WS_EVT_DISCONNECT) {
        Serial.println("Connnection Closed");
        Serial.printf("WebSocket client #%u disconnected\n", client->id());
    } else if (type == WS_EVT_DATA) {
        Serial.println("Got a Data!");
        websocket_handle_message(arg, data, len);
    } else if (type == WS_EVT_ERROR) {
        Serial.println("Got a Error!");
    }
}



// ----------------------------------------------------------------------------------------
// Inisialisasi protokol websocket
// ----------------------------------------------------------------------------------------
void websocket_init() {
    ws.onEvent(websocket_onEvent);
    server.addHandler(&ws);
}


// ----------------------------------------------------------------------------------------
// Pembacaan nilai adc pada modul PCF8591
// ----------------------------------------------------------------------------------------
uint8_t pcf8591_read() {
    uint8_t adcvalue0, adcvalue1, adcvalue2, adcvalue3;

    // Mulai komunikasi dengan modul PCF 
    Wire.beginTransmission(PCF8591);
    Wire.write(0x04);
    Wire.endTransmission();
    Wire.requestFrom(PCF8591, 5);
    
    // Baca nilai jarak
    adcvalue0 = Wire.read();
    adcvalue0 = Wire.read();
    adcvalue1 = Wire.read();
    adcvalue2 = Wire.read();
    adcvalue3 = Wire.read();

    // Ambil nilai adc0 karena sensor terhubung ke pin adc0 (A0)
    return adcvalue0;
}


// ----------------------------------------------------------------------------------------
// Membaca jarak dengan satuan cm 
// ----------------------------------------------------------------------------------------
uint16_t read_distance_cm(){

    // Baca nilai sensor dari modul pcf
    uint16_t adc = pcf8591_read();

    // Hitung tegangan dari nilai adc
    voltage = (adc * 5) / 255.0;

    // Konversi nilai adc menjadi nilai jarak satuan cm
    return to_infrared_distance(adc);
}


// ----------------------------------------------------------------------------------------
// Mengkonversi nilai adc mencjadi nilai jarak (cm)
// ----------------------------------------------------------------------------------------
uint16_t to_infrared_distance(uint16_t value){

    // Konversi nilai adc dari 8 bit adc menjadi 10 bit adc
	value = map(value, 0, 255, 0, 1023);
	
    // Apabila nilai adc antara 280-512 (apabila dikonversi cm menjadi 550cm sampai 100cm)
    if (value >= 280 && value <= 512)
    return 28250/(value-229.5);     // Hitung nilai jarak 
    
    // Apabila nilai adc diluar batas
    else return OUT_OF_RANGE;       // Diluar batas

}



// ----------------------------------------------------------------------------------------
// Melakukan banyak pengukuran kemudian mengurutkan dan mengambil nilai median
// ----------------------------------------------------------------------------------------
//      Misal dalam 5x pengukuran mendapatkan hasil 100, 330, 220, 150, 225
//      Setelah data dirutkan menjadi 100, 150, 220, 225, 330
//      Setelah diambil nilai tengah/median yaitu 220 cm
// ----------------------------------------------------------------------------------------
uint16_t read_median(uint8_t it, bool sensor) {
	uint16_t dist[it], last;
	uint8_t j, i = 0;
	dist[0] = OUT_OF_RANGE;

	while (i < it) {
    
    	if (sensor == SENSOR_ULTRASONIC)
		  last = ping_cm();
		else 
		  last = read_distance_cm();  
    

		if (last != OUT_OF_RANGE) {      
			if (i > 0) {            
				for (j = i; j > 0 && dist[j - 1] < last; j--){
					dist[j] = dist[j - 1];                     
				}
			} else {
				j = 0;
			}       

			dist[j] = last;              
			i++;                       
		} else {
			it--;                   
		} 
	}
	return (dist[it >> 1]); 
}


float ping_cm(){
	long duration;
	
	digitalWrite(TRIGGER_PIN, LOW);
	delayMicroseconds(2);
	digitalWrite(TRIGGER_PIN, HIGH);
	delayMicroseconds(10);
	digitalWrite(TRIGGER_PIN, LOW);
	
	duration = pulseIn(ECHO_PIN, HIGH);
	return duration * SOUND_VELOCITY / 2;
}

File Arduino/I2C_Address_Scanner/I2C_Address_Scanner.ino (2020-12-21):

#include "Wire.h"

void setup(){
    Serial.begin(115200); 
    while(!Serial){} // Waiting for serial connection
 
    Serial.println();
    Serial.println("Start I2C scanner ...");
    Serial.print("\r\n");
    byte count = 0;
  
    Wire.begin();
    for (byte i = 8; i < 120; i++) {
        Wire.beginTransmission(i);
        if (Wire.endTransmission() == 0) {
            Serial.print("Found I2C Device: ");
            Serial.print(" (0x");
            Serial.print(i, HEX);
            Serial.println(")");
            count++;
            delay(1);
        }
    }
    Serial.print("\r\n");
    Serial.println("Finish I2C scanner");
    Serial.print("Found ");
    Serial.print(count, HEX);
    Serial.println(" Device(s).");
}

void loop() {}

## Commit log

2020-12-08 - Struktur program baru - Masih banyak bug - Belum di test
2020-12-11 - Struktur program baru - Penambahan Field Foto Kendaraan - Fix Leaked SQLite
    [VehicleMeasuring.ino]
2020-12-21 - Penambahan LCD - Perubahan Skema - Perubahan Library WebSocket - Penambahan Flowchart
    [skema.fzz]
2020-12-21 - Perubahan Flowchart Arduino
2021-01-19 - Perubahan sensor jarak ke Sharp GP2Y0A710K0F - Update Skema
    [skema.fzz]
2021-04-17 - Penambahan penjelasan library pada program arduino
2021-04-19 - Penambahan link library arduino
2021-08-08 - Penambahan sensor ultrasonic
2021-08-08 - Penambahan penjelasan program - Perubahan skema rangkaian - Perubahan flowchart
    [skema.fzz]
2021-08-09 - Penambahan flowchart
2021-08-09 - Fix gambar flowchart
